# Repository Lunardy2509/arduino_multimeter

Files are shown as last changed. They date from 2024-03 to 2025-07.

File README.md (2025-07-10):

<details>
<summary>Click to view Documentation Images</summary>
  
| | | |
|---|---|---|
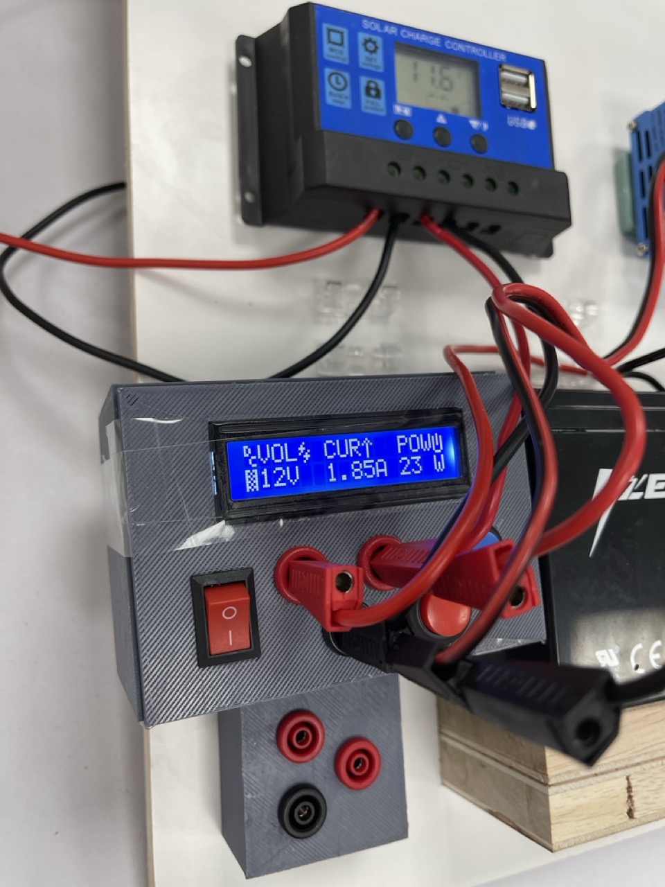
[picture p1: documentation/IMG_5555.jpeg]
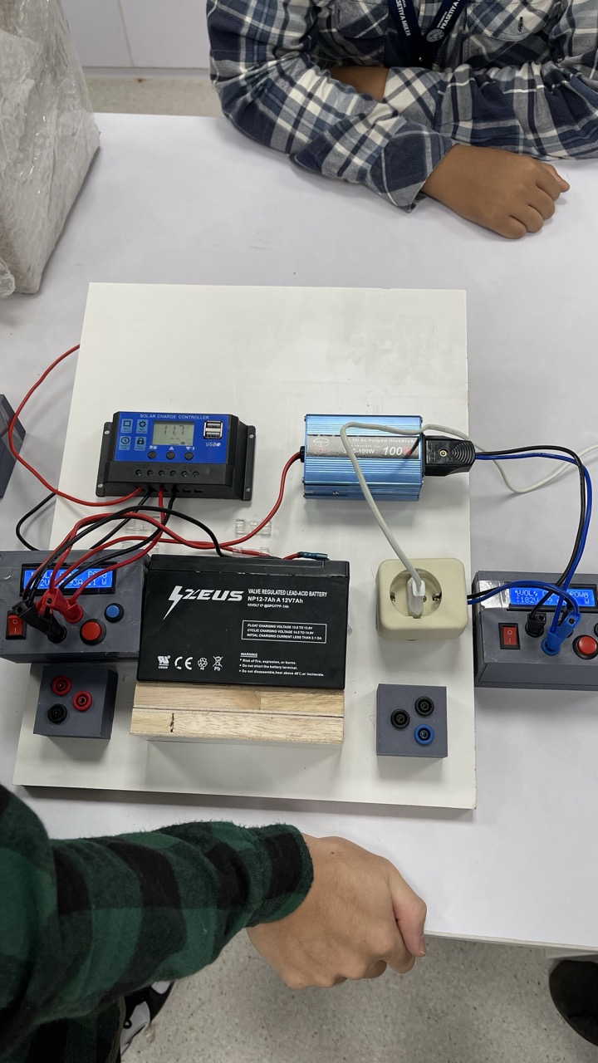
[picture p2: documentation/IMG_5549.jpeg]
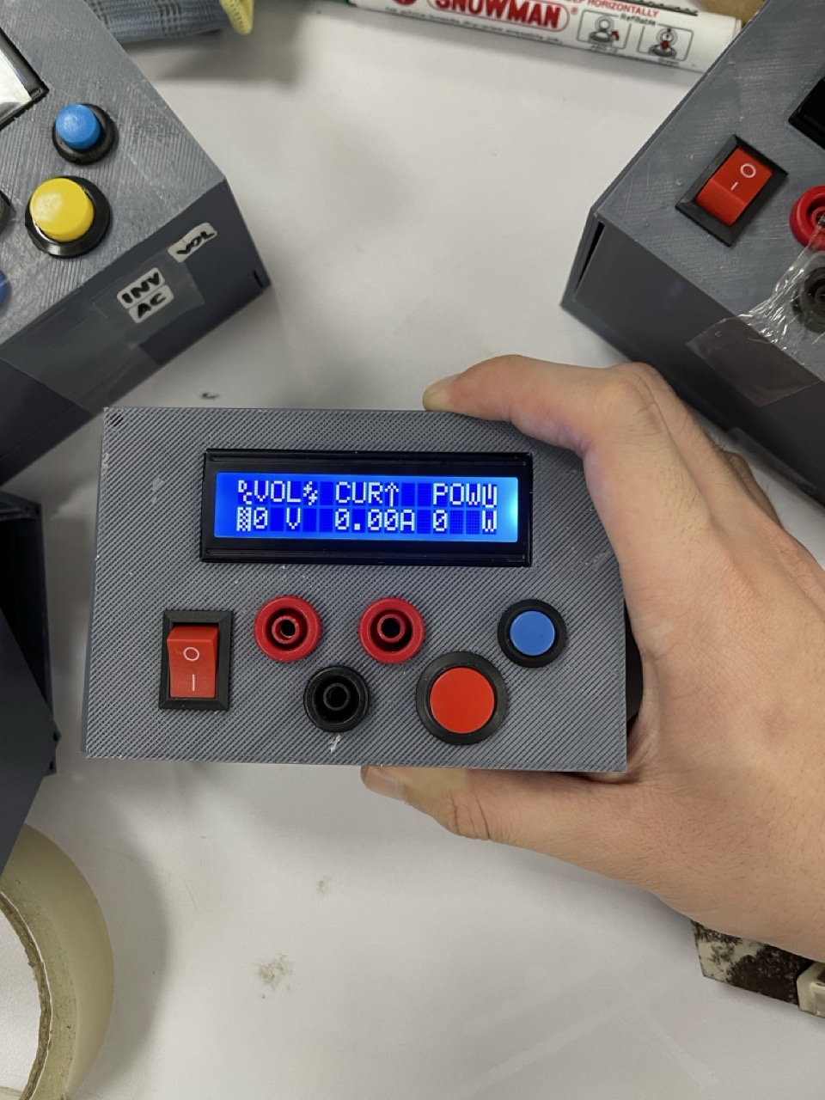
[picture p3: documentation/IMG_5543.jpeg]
|  |  |  |

</details>

# 🔧 Arduino-Based Multimeter for Solar Power Monitoring

This is an open-source Arduino project designed to function as a **custom multimeter** capable of measuring DC and AC current (up to 5A) for solar PV systems. Developed under the *PKM MAN IC* initiative, this project supports solar education by enabling students to monitor real-time voltage, current, and power (watts) in small-scale solar setups.

---

## 📌 Project Objective

The multimeter is used to:

- ✅ Measure **input and output voltage/current** from solar PV systems
- ✅ Monitor components like **12V 3A battery**, **inverters**, and **loads** (e.g., electric fans)
- ✅ Hold/freeze values for user review via button interface

This was built for educational purposes in a high school community service program (*Pengabdian Kepada Masyarakat*) at **MAN Insan Cendekia Serpong** in Tangerang Selatan, Indonesia.

---

## ⚙️ Features

- 🧪 Measures both **DC and AC current** up to 5A  
- 🔋 Supports **solar PV + battery + inverter** system testing  
- 🖥️ Displays live voltage, current, and power  
- ⏸️ Includes **HOLD** function to freeze displayed values  
- 💾 Can log and compare values for calibration (with Excel sheet)  

---

## 📁 Folder Structure

```bash
arduino_multimeter/
├── circuit schematics/               # Wiring and circuit design (Fritzing/PNG)
├── code/                             # Arduino sketch (.ino)
│   └── multimeter.ino
├── documentation/                    # Educational docs or guides
├── Example_Sensor_Calibration.xlsx   # Calibration data for sensors
├── List of Materials and Apparatus.xlsx
└── README.md
```

## 🔌 Hardware Components
| Component | Quantity | Description |
| --- | --- | --- |
| Arduino Uno / Nano | 1 | Microcontroller base |
| ACS712 / INA219 Sensor | 1–2 | Current sensor (for 5A current) |
| Voltage Divider | 1 | For voltage measurement |
| OLED / LCD Display | 1 | For live data readout |
| Push Button | 1 | To hold/freeze values |
| Load (e.g., Electric Fan) | 1 | Used as demonstration load |
| Solar PV Panel (12V) | 1 | Input source |
| Battery (12V, 3A) | 1 | Intermediate storage |
| Wires, Breadboard, etc. | - | For circuit assembly |

## 🧰 Required Libraries
Please install the following libraries in your Arduino IDE:
- `Wire.h` (built-in)
- `LiquidCrystal_I2C.h` or `Adafruit_SSD1306.h` (based on display type)
- `ACS712.h` or `INA219.h` (based on current sensor)
Install via: **Sketch** → **Include Library** → **Manage Libraries**

## 🚀 Getting Started
### 1. Clone the Repository
```bash
git clone https://github.com/Lunardy2509/arduino_multimeter.git
cd arduino_multimeter/code
```

### 2. Upload Code
- Open `multimeter.ino` in Arduino IDE
- Install required libraries (see above)
- Select your board and COM port
- Upload the sketch to your Arduino

### 3. Build the Circuit
- Use the diagrams in `circuit schematics/` to connect your sensors and display
- Power the setup using USB or external 12V source (when appropriate)

## 📊 Calibration & Data Logging
Use `Example_Sensor_Calibration.xlsx` to:
- Calibrate raw sensor data against known values
- Adjust coefficients in your code accordingly for better accuracy

## 📚 Acknowledgments
This project was developed as part of a school community service program under PKM MAN IC (Pengabdian Kepada Masyarakat Madrasah Aliyah Negeri Insan Cendekia). Special thanks to the school and students involved in the solar energy education program.

## 📬 Contact
- GitHub: [@Lunardy2509](https://github.com/Lunardy2509)
- Email: ferdilunardy@gmail.com

If this helped your solar learning journey, please consider giving a ⭐️ and sharing with fellow makers!

---

Let me know if you want:
- A Bahasa Indonesia version
- Visual system diagrams or GIFs
- PDF export of documentation

I'll be happy to assist!

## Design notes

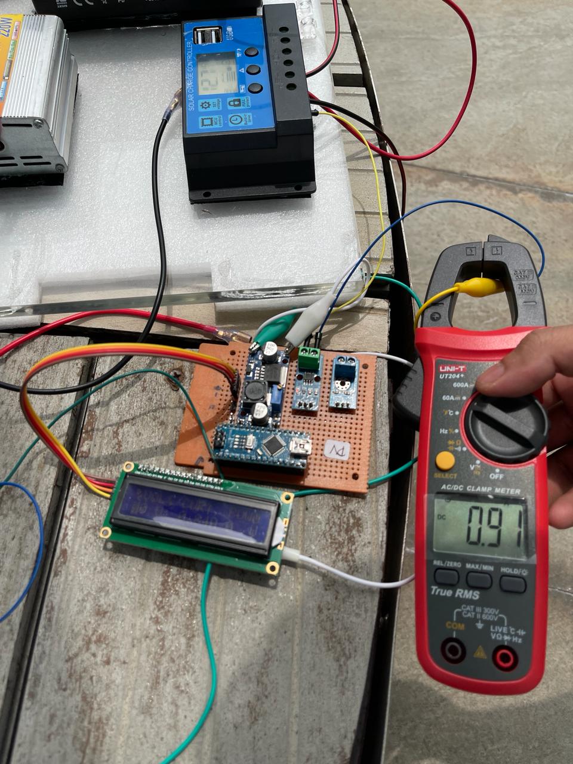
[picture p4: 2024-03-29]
documentation/IMG-20240329-WA0020.jpg

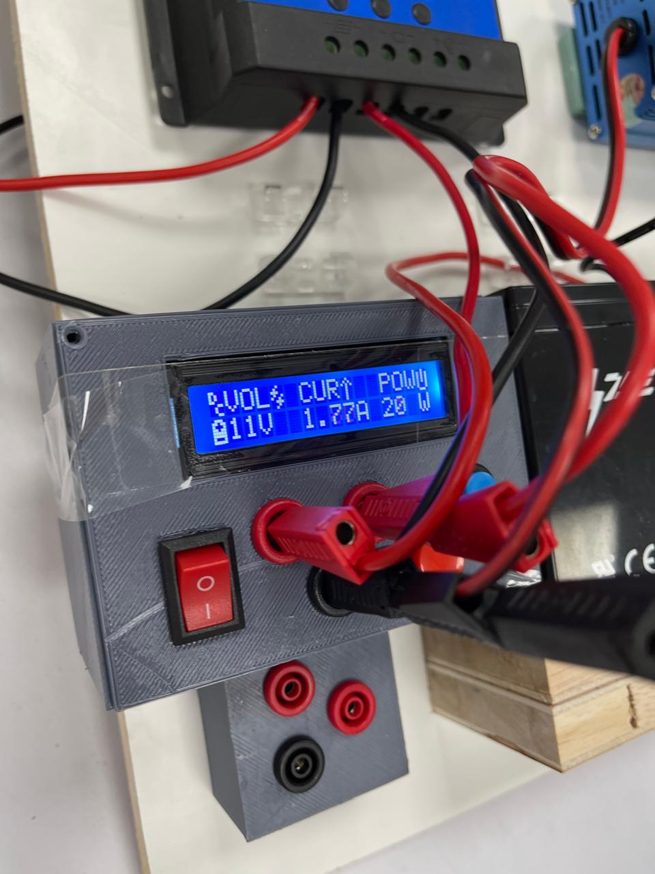
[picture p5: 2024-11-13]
documentation/WhatsApp Image 2024-11-13 at 11.24.08_102a96aa.jpg

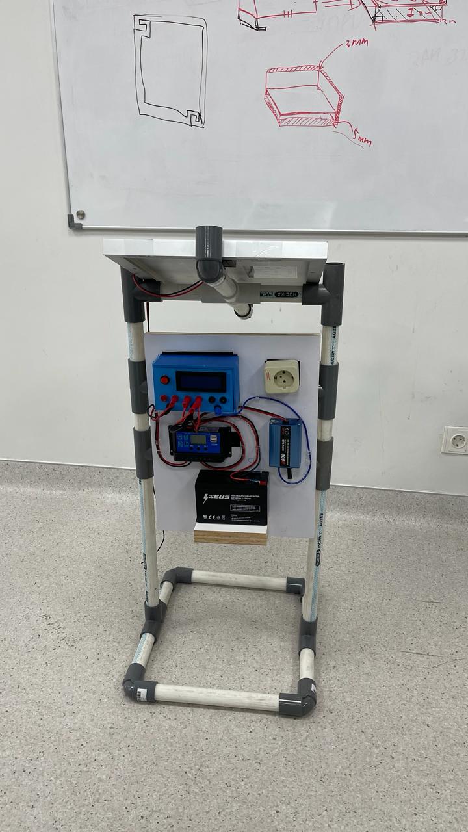
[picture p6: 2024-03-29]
documentation/IMG-20240329-WA0017.jpg

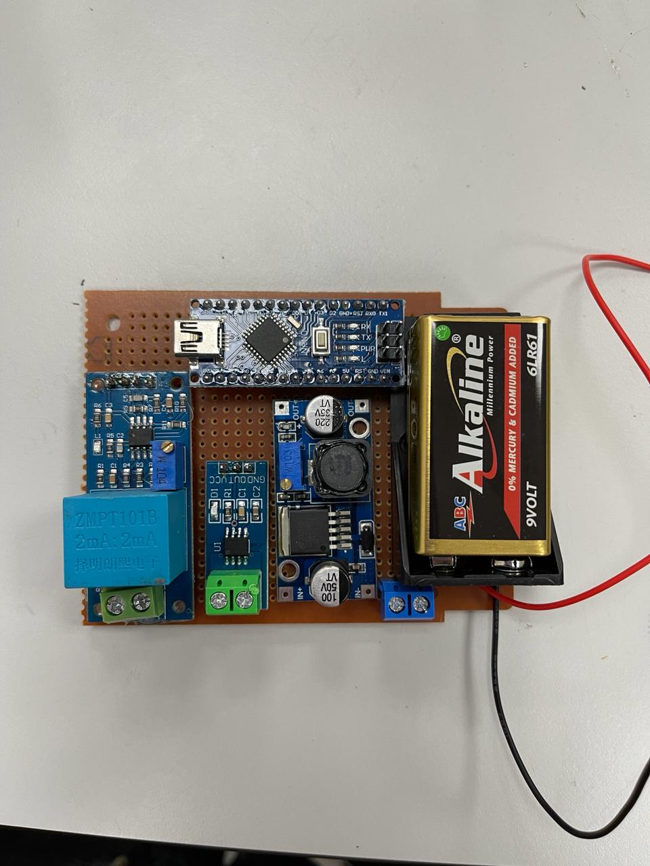
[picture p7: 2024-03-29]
documentation/IMG-20240329-WA0018.jpg

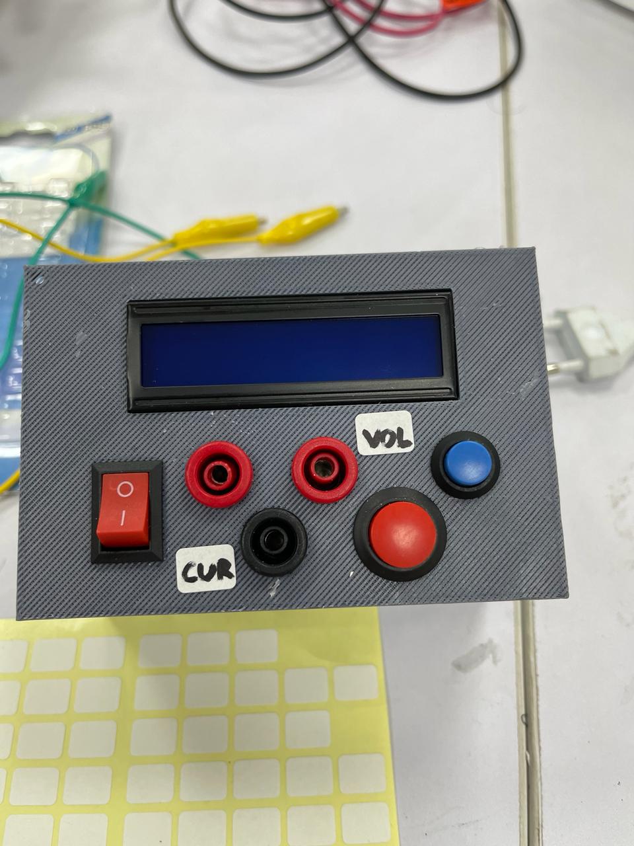
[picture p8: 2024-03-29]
documentation/IMG-20240329-WA0019.jpg

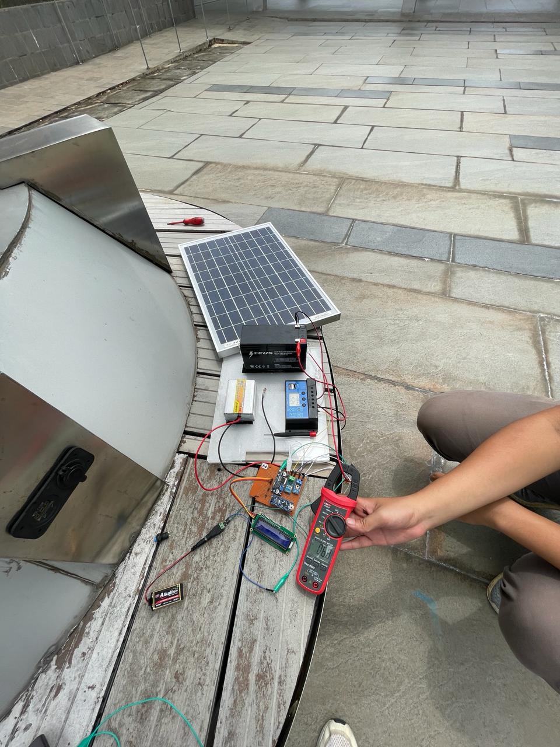
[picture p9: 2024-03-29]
documentation/IMG-20240329-WA0016.jpg

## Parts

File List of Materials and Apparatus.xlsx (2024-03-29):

No. | Materials and Apparatus
1 | Arduino Nano V3
2 | lm2596 Step Down DC converter
3 | LCD 16x2 I2C
4 | Voltage Sensor DC VCC < 25V
5 | Voltage Sensor AC ZMPT101B
6 | Current Sensor DC ACS712 5A
7 | Current Sensor AC ACS712 5A
8 | Battery 9V Alkaline

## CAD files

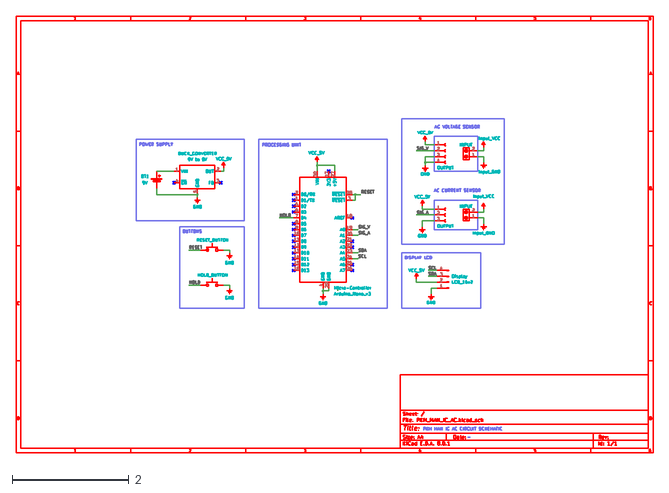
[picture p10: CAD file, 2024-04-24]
circuit schematics/PKM_MAN_IC_AC.dxf
10.9 x 7.48

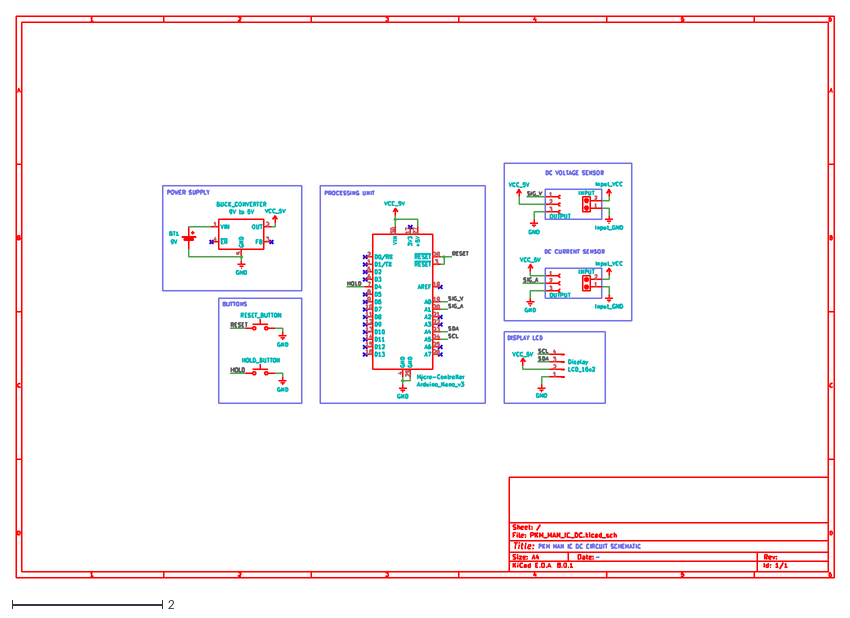
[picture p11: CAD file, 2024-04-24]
circuit schematics/PKM_MAN_IC_DC.dxf
10.9 x 7.48

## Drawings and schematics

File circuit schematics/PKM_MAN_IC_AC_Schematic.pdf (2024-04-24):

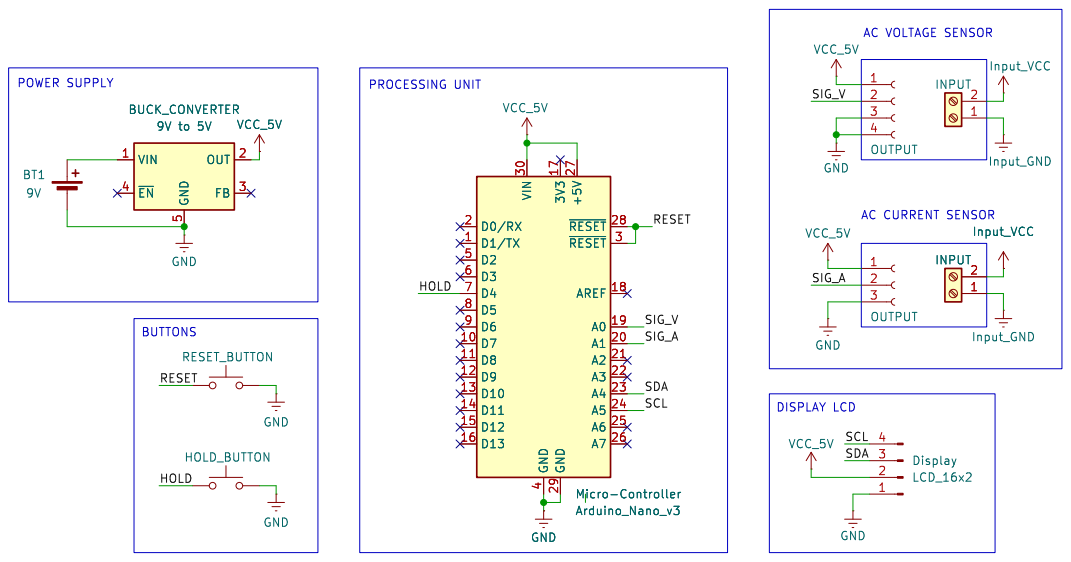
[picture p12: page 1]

5 Micro-Controller Arduino_Nano_v3 D1/TX 1 D7 10 D8 11 D9 12 D10 13 D11 14 D12 15 D13 16 3V3 17 AREF 18 A0 19 D0/RX 2 A1 20 A2 21 A3 22 A4 23 A5 24 A6 25 A7 26 +5V 27

Id: 1/1 Title: File: PKM_MAN_IC_AC.kicad_sch Sheet: /

PKM MAN IC AC CIRCUIT SCHEMATIC

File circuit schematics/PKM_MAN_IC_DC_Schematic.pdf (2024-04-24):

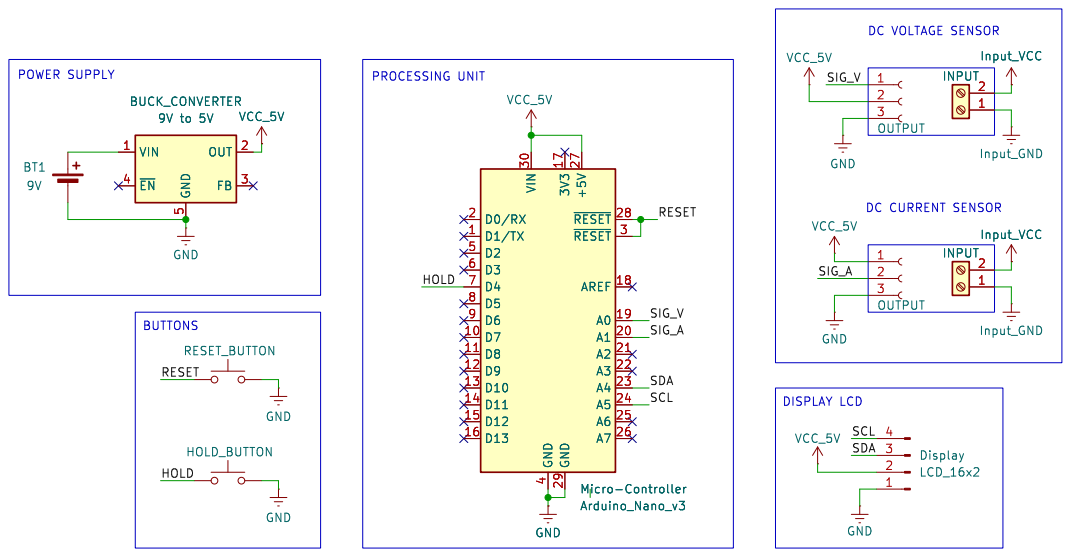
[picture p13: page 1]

Id: 1/1 Title: File: PKM_MAN_IC_DC.kicad_sch Sheet: /

PKM MAN IC DC CIRCUIT SCHEMATIC

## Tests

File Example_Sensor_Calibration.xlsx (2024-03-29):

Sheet: Sheet1
A. | AC Volt Calibration
 | No Data. | Real Reading | Sensor Reading | Unit | Error Rate
 | 1 | 10 | 10 | V | 0
 | 2 | 20 | 18 | V | 0.1
 | 3 | 40 | 36 | V | 0.1
 | 4 | 60 | 51 | V | 0.15
 | 5 | 80 | 61 | V | 0.2375
 | 6 | 100 | 84 | V | 0.16
 | 7 | 120 | 93 | V | 0.225
 | 8 | 140 | 110 | V | 0.2142857143
 | 9 | 160 | 129 | V | 0.19375
 | 10 | 180 | 146 | V | 0.1888888889
 | 11 | 200 | 160 | V | 0.2
 | 12 | 220 | 171 | V | 0.2227272727
B. | DC Volt Calibration
 | No Data. | Real Reading | Sensor Reading | Unit | Error Rate
 | 1 | 0.4 | 0.1 | V | 0.75
 | 2 | 2.506 | 2.3 | V | 0.08220271349
 | 3 | 4.45 | 4.3 | V | 0.03370786517
 | 4 | 6.41 | 6.3 | V | 0.01716068643
 | 5 | 8.47 | 8.3 | V | 0.02007083825
 | 6 | 10.4 | 10.4 | V | 0
 | 7 | 12.49 | 12.1 | V | 0.03122497998
 | 8 | 14.27 | 14.6 | V | 0.02312543798
 | 9 | 16.4 | 16.3 | V | 0.006097560976
 | 10 | 18.38 | 18.3 | V | 0.004352557127
 | 11 | 20.11 | 24.9 | V | 0.2381899552
 | 12 | 22.1 | 24.7 | V | 0.1176470588
B. | DC Volt Calibration
 | No Data. | Real Reading | Sensor Reading | Unit | Error Rate | Sensor 2
 | 1 | 0 | 0 | V | 0
 | 2 | 1.02 | 0.9 | V | 0.1176470588
 | 3 | 2.06 | 2 | V | 0.02912621359
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

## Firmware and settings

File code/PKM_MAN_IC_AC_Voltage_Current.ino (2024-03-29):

#include <Wire.h>               // Library for Wire
#include <LiquidCrystal_I2C.h>  // Library for LCD using I2C communication
#include <ACS712.h>             // Library for ACS712 Current Sensor
#include <ZMPT101B.h>           // Library for ZMPT101B AC Voltage Sensor
#include <EEPROM.h>             // Library for store and read data in memory
#define SENSITIVITY 500.0f
LiquidCrystal_I2C lcd(0x27, 16, 2);
int vInv, cal_VInv, Pow_Inv;
float iInv, cal_iInv, average;

//for EEPROM Store Data
int buttonPin = 4;
int buttonState = 0;
int ledPin = 3;
int address = 0;
bool updateData = true;
//

ACS712 ACS(A1, 5.0, 1023, 185);
//  Arduino UNO has 5.0 volt with a max ADC value of 1023 steps
//  ACS712 5A  uses 185 mV per A
//  ACS712 20A uses 100 mV per A
//  ACS712 30A uses  66 mV per A
uint32_t start, stop;

// ZMPT101B sensor output connected to analog pin A6
// and the voltage source frequency is 50 Hz.
ZMPT101B voltageSensor(A0, 50.0);

//SYMBOLS
byte Inv[] = { 0b00100, 0b01010, 0b00100, 0b00000, 0b00100, 0b01010, 0b00100, 0b00000 };
byte AC[] = { 0b01000, 0b10100, 0b11100, 0b10100, 0b00011, 0b00100, 0b00100, 0b00011 };
byte Vol[] = { 0b00100, 0b01000, 0b11100, 0b01001, 0b10010, 0b00111, 0b00010, 0b00100 };
byte Cur[] = { 0b00100, 0b01010, 0b10101, 0b00100, 0b00100, 0b00100, 0b00100, 0b00100 };
byte Pow[] = { 0b00100, 0b10101, 0b10101, 0b10101, 0b10101, 0b10001, 0b10001, 0b01110 };

void
setup() {
  Serial.begin(9600);
  pinMode(buttonPin, INPUT_PULLUP);
  pinMode(ledPin, OUTPUT);
  Wire.begin();
  voltageSensor.setSensitivity(SENSITIVITY);
  lcd.init();
  lcd.backlight();
  lcd.setBacklight(HIGH);
  lcd.createChar(1, AC);
  lcd.createChar(2, Inv);
  lcd.createChar(3, Vol);
  lcd.createChar(4, Cur);
  lcd.createChar(5, Pow);
}

void CalACVolt() {
  vInv = voltageSensor.getRmsVoltage();
  cal_VInv = (vInv - 0.7436) / 0.9698;
  if (cal_VInv < 20) {
    cal_VInv = 0;
  }
  // Serial.print("Vinv: ");
  // Serial.println(vInv);
  // Serial.print("calibrated: ");
  // Serial.println(cal_VInv);
  delay(500);
}

void CalACCurrent() {
  average = 0;
  for (int i = 0; i < 100; i++) {
    average += ACS.mA_AC();
  }
  iInv = average / 100.0;
  iInv = iInv / 1000;
  cal_iInv = (iInv - 0.2373) / 0.4419;
  if (cal_iInv <= 0.04) {
    cal_iInv = 0.0;
  }
  // Serial.println(iInv);
  // Serial.println(cal_iInv);
  delay(500);
}

void CalPower() {
  //Power for Inverter
  Pow_Inv = cal_VInv * cal_iInv * 0.54;
}

void loop() {
  CalACVolt();
  CalACCurrent();
  CalPower();
  if (updateData) {
    // Store values in EEPROM only if updateData is true
    EEPROM.write(address, static_cast<byte>(cal_VInv));
    EEPROM.write(address + 1, static_cast<byte>(cal_iInv));
    EEPROM.write(address + 2, static_cast<byte>(Pow_Inv));
  }
  buttonState = digitalRead(buttonPin);
  //Create table in LCD
  //Make the output more observable for customer
  lcd.setCursor(1, 0);
  lcd.print("VOL");
  lcd.write(3);  //Logo for Voltage
  lcd.setCursor(6, 0);
  lcd.print("CUR");
  lcd.write(4);  //Logo for Current
  lcd.setCursor(12, 0);
  lcd.print("S");
  lcd.write(5);  //Logo for Power
  lcd.setCursor(0, 0);
  lcd.write(1);  //Logo for Inverter
  lcd.setCursor(0, 1);
  lcd.write(2);  //Logo for AC
  //End of Table Design
  if (buttonState == LOW) {
    // Read values from EEPROM and send them over Serial
    updateData = false;  // Stop updating data
    // digitalWrite(ledPin, HIGH);
    lcd.setCursor(1, 1);
    lcd.print(EEPROM.read(address));
    lcd.setCursor(4, 1);
    lcd.print("V");
    lcd.setCursor(6, 1);
    lcd.print(EEPROM.read(address + 1));
    lcd.setCursor(10, 1);
    lcd.print("A");
    lcd.setCursor(12, 1);
    lcd.print(EEPROM.read(address + 2));
    lcd.setCursor(14, 1);
    lcd.print("VA");
  } else {
    //Start giving output data here:
    //Measure Inverter's Voltage...
    lcd.setCursor(1, 1);
    lcd.print(cal_VInv);
    lcd.setCursor(4, 1);
    lcd.print("V");
    //End of first column

    //Measure Inverter's Current
    lcd.setCursor(6, 1);
    lcd.print(cal_iInv);
    lcd.setCursor(10, 1);
    lcd.print("A");
    //End of second column

    //Calculation of Power using "P = V * I" formula
    //Inverter's Power:
    lcd.setCursor(12, 1);
    lcd.print(Pow_Inv);
    lcd.setCursor(14, 1);
    lcd.print("VA");
    // Resume updating data
    updateData = true;
  }
  delay(1000);  // Add a small delay for stability, if needed
}

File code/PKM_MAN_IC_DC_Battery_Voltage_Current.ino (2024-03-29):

#include <Wire.h>               // Library for Wire
#include <LiquidCrystal_I2C.h>  // Library for LCD using I2C communication
#include <EEPROM.h>             // Library for store and read data in memory
LiquidCrystal_I2C lcd(0x27, 16, 2);
String Data;
char c;

//for EEPROM Store Data
int buttonPin = 4;
int buttonState = 0;
int ledPin = 3;
int address = 0;
bool updateData = true;
//

const int numReadings1 = 10;
int readings1[numReadings1];
int readIndex1 = 0;
int total1 = 0;

const int numReadings2 = 10;
int readings2[numReadings2];
int readIndex2 = 0;
int total2 = 0;

double batasarus = 2485;
double naikarus = 185;

int adctegangan1, adctegangan2, tegangan, tegangan2, Pow_Bat;
float vBat, cal_vol_bat, cal_cur_bat, arusdc, arusdc1, iBat, average;
double adcarus, adcarus1, varus, varus1;

//SYMBOLS
byte Bat[] = { 0b01110, 0b11011, 0b10001, 0b11011, 0b11111, 0b11111, 0b10001, 0b11111 };
byte DC[] = { 0b11000, 0b10100, 0b10100, 0b11000, 0b00011, 0b00100, 0b00100, 0b00011 };
byte Vol[] = { 0b00100, 0b01000, 0b11100, 0b01001, 0b10010, 0b00111, 0b00010, 0b00100 };
byte Cur[] = { 0b00100, 0b01010, 0b10101, 0b00100, 0b00100, 0b00100, 0b00100, 0b00100 };
byte Pow[] = { 0b00100, 0b10101, 0b10101, 0b10101, 0b10101, 0b10001, 0b10001, 0b01110 };

void setup() {
  // put your setup code here, to run once:
  Serial.begin(9600);
  pinMode(buttonPin, INPUT_PULLUP);
  pinMode(ledPin, OUTPUT);
  Wire.begin();
  lcd.init();
  lcd.backlight();
  lcd.setBacklight(HIGH);
  lcd.createChar(1, DC);
  lcd.createChar(2, Bat);
  lcd.createChar(3, Vol);
  lcd.createChar(4, Cur);
  lcd.createChar(5, Pow);
}

void CalDCVolt() {
  //Battery's Voltage DC
  //PV's Voltage DC
  adctegangan1 = analogRead(A0);
  total2 = total2 - readings2[readIndex2];
  readings2[readIndex2] = adctegangan1;
  total2 = total2 + readings2[readIndex2];
  readIndex2 = readIndex2 + 1;
  if (readIndex2 >= numReadings2) {
    readIndex2 = 0;
  }
  adctegangan1 = total2 / numReadings2;
  tegangan = map(adctegangan1, 0, 1024, 0, 250);
  vBat = tegangan / 10.0;
  cal_vol_bat = (vBat + 0.1) / 1;
  if (cal_vol_bat <= 0.2) {
    cal_vol_bat = 0.0;
  }
  // Serial.print("Voltage vBat: ");
  // Serial.println(cal_vol_bat);
}


void CalDCCurBat(){
  //DCCurrentBat
  adcarus1 = analogRead(A1);
  total1 = total1 - readings1[readIndex1];
  readings1[readIndex1] = adcarus1;
  total1 = total1 + readings1[readIndex1];
  readIndex1 = readIndex1 + 1;
  if (readIndex1 >= numReadings1) {
    readIndex1 = 0;
  }
  adcarus1 = total1 / numReadings1;
  varus1 = (adcarus1 / 1024.0) * 5000;
  arusdc1 = ((varus1 - batasarus) / naikarus);
  cal_cur_bat = (arusdc1 + 0.6073) / 1.1482;
  if (cal_cur_bat <= 0.05) {
    cal_cur_bat = 0.0;
  }
  Serial.print("DC CURRENT: ");
  // Serial.println(cal_cur_bat);
  Serial.println(arusdc1);
  delay(500);
}

void CalPower() {
  //Power for Battery
  Pow_Bat = cal_vol_bat * cal_cur_bat;
}

void loop() {
  // put your main code here, to run repeatedly:
  CalDCVolt();
  CalDCCurBat();
  CalPower();
  if (updateData) {
    // Store values in EEPROM only if updateData is true
    EEPROM.write(address, static_cast<byte>(cal_vol_bat));
    EEPROM.write(address + 1, static_cast<byte>(cal_cur_bat));
    EEPROM.write(address + 2, static_cast<byte>(Pow_Bat));
  }
  buttonState = digitalRead(buttonPin);
  //Create table in LCD
  //Make the output more observable for customer
  lcd.setCursor(1, 0);
  lcd.print("VOL");
  lcd.write(3);  //Logo for Voltage
  lcd.setCursor(6, 0);
  lcd.print("CUR");
  lcd.write(4);  //Logo for Current
  lcd.setCursor(12, 0);
  lcd.print("POW");
  lcd.write(5);  //Logo for Power
  lcd.setCursor(0, 0);
  lcd.write(1);  //Logo for DC
  lcd.setCursor(0, 1);
  lcd.write(2);  //Logo for Battery
  //End of Table Design
  if (buttonState == LOW) {
    // Read values from EEPROM and send them over Serial
    updateData = false;  // Stop updating data
    // digitalWrite(ledPin, HIGH);
    lcd.setCursor(1, 1);
    lcd.print(EEPROM.read(address));
    lcd.setCursor(5, 1);
    lcd.print("V");
    lcd.setCursor(6, 1);
    lcd.print(EEPROM.read(address + 1));
    lcd.setCursor(10, 1);
    lcd.print("A");
    lcd.setCursor(12, 1);
    lcd.print(EEPROM.read(address + 2));
    lcd.setCursor(15, 1);
    lcd.print("W");
  } else {
    //Start giving output data here:
    //Measure Battery's Voltage...
    lcd.setCursor(1, 1);
    lcd.print(cal_vol_bat);
    lcd.setCursor(5, 1);
    lcd.print("V");
    //End of first column

    //Measure Battery's Current
    lcd.setCursor(6, 1);
    lcd.print(cal_cur_bat, 2);
    lcd.setCursor(10, 1);
    lcd.print("A");
    //End of second column

    //Calculation of Power using "P = V * I" formula
    //Battery's Power:
    lcd.setCursor(12, 1);
    lcd.print(Pow_Bat);
    lcd.setCursor(15, 1);
    lcd.print("W");
    // Resume updating data
    updateData = true;
  }
  delay(1000);  // Add a small delay for stability, if needed
}
